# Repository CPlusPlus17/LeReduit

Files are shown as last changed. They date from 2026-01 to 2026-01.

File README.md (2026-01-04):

# 🏔️ Le Réduit

> **Autonomous Server: Solar, LoRa, WLAN & SSD. Your digital fortress for communication & situational awareness in emergencies.**






## 📖 About the Project

**Le Réduit** is a tribute to the Swiss National Redoubt strategy: A final, secure bastion when everything else fails.

This project documents the construction of a portable, energy-autonomous IT infrastructure inside a standardized Eurobox (Rako case). The system transforms a Raspberry Pi 4 into a **Tactical Operations Center (TOC)** for:
1.  **Situational Awareness & Command:** Real-time tracking and maps via TAK (Team Awareness Kit).
2.  **Secure Communication:** Encrypted chat and VoIP without the internet.
3.  **Radio Bridge:** Integration of LoRa (Meshtastic) into IP networks.
4.  **Emergency Power Supply:** Massive 100Ah battery capacity for days of operation without sun.

## ✨ Features

* **🔋 Energy Autonomy:** 100W/200W foldable solar panel + Victron SmartSolar MPPT 100/20 + 100Ah LiFePO4 battery.
* **📡 Off-Grid Communication:**
    * **LoRa:** Meshtastic Node (868 MHz) for communication over kilometers without mobile networks.
    * **LTE:** 4G/Cat-1 Bridge for hybrid connectivity when mobile networks are available.
    * **WLAN:** High-Power Access Point (Atheros AR9271) for local team devices.
* **🛡️ Edge Cluster:** Operates as a Single-Node Kubernetes Cluster (k3s) for maximum stability and "Infrastructure as Code".
* **💾 Hardware:** Passively cooled aluminum housing ("Armor Case"), insulated Rako case, IP-certified feedthroughs.

---

## 🛠️ Hardware (Bill of Materials)

A detailed shopping list can be found in [BOM.md](BOM.md). Here are the main components:

### ⚡ Energy
* **Battery:** Hypery Smart 12V LiFePO4 (100Ah, Bluetooth, BMS)
* **Solar:** 100W/200W Foldable Panel & Victron SmartSolar MPPT 100/20
* **Charging:** SAE External Port & PACO 10A Mains Charger (Backup)
* **Monitoring:** Digital Voltmeter & Fuse Holder (16AWG)

### 🖥️ Compute & Network
* **SBC:** Raspberry Pi 4 Model B (8GB RAM)
* **Storage:** Intenso TOP SSD (256GB, SATA III) + USB 3.0 Adapter
* **LoRa:** Heltec WiFi LoRa 32 V3 (ESP32)
* **WiFi:** Atheros AR9271 USB Adapter (with external antenna)
* **LTE:** USB A7670G LTE Cat 1 Dongle (Global Bands)
* **RTC:** DS3231 Real Time Clock (for timestamps without internet)

### 📦 Enclosure
* **Box:** Rako Container 600x400mm (60 Liters)
* **Structure:** Poplar plywood "Tech Deck" & Beechwood slat fixation
* **Insulation:** XPS Jackodur (20mm) for winter operation

---

## 🔌 Wiring & Architecture

The system follows a star-shaped 12V topology with central fusing.

See the [Detailed Wiring Schema](docs/wiring_schema.md) for the complete Mermaid diagram and pinout.

**Key Connections:**
* **Solar Input:** SAE Socket -> MPPT Controller
* **Load:** MPPT Load -> Main Switch -> Distributor -> DC-DC Converter -> Pi 4
* **Data:** SSD on USB 3.0 (Blue), Radio Modules on USB 2.0 (Interference Avoidance).

---

## 💻 Software Stack: "Edge Kubernetes Cluster"

The system runs as a **Single-Node Kubernetes Cluster** based on **k3s**. This enables "Self-Healing" capabilities (if a service crashes, it is restarted) and professional deployment via **Helm Charts**.

### 🏗️ Orchestration & Core
* **OS:** Raspberry Pi OS Lite (64-bit)
* **Cluster:** [k3s](https://k3s.io/) (Lightweight Kubernetes, optimized for Edge/IoT).
* **Package Management:** **Helm**. All services are defined as charts.
* **Ingress:** **Traefik** or **Nginx Ingress** for routing internal domains (e.g., `tak.reduit.local`).
* **Cert-Manager:** Manages internal self-signed certificates for TLS encryption.

### 🗺️ Situational Awareness
* **[OpenTAKServer](https://github.com/TakServer/OpenTakServer):**
    * Deployed via Helm Chart.
    * Central server for **ATAK** (Android Team Awareness Kit) clients.
    * Provides position data, markers, chat, and "Data Packages" to all connected end devices.
    * Hosts offline map tiles for the operational area.

### 💬 Secure Comms
* **[Matrix](https://matrix.org/):**
    * High-Performance Matrix Server (written in Rust).
    * Offers E2EE (End-to-End Encrypted) chats and file sharing.
    * Extremely resource-efficient compared to Synapse.
* **[Mumble](https://www.mumble.info/):**
    * VoIP server for tactical voice communication with low latency.
    * Works reliably even with unstable connections.

### 📡 Radio Bridge & Tools
* **[Meshtastic-Bridge](https://meshtastic.org/):**
    * Custom Pod that mirrors messages from the LoRa USB stick into a Matrix room via Python API.
    * Enables communication between WLAN users (ATAK/Matrix) and distant LoRa nodes.

---

## ⚠️ Safety Warning

This project uses large energy storage (LiFePO4 batteries).
* **Short Circuit Hazard:** A 100Ah battery can melt cables and cause fires in case of a short circuit. Fuses are mandatory!
* **BMS & Monitoring:** The LiFePO4 battery has an integrated BMS, but external fusing remains mandatory. Bluetooth monitoring allows checking cell status.

## 🤝 Contributing

Pull Requests for Helm Charts, 3D printed parts (mounts), or configuration tips are welcome!

## 📄 License

This project is published under the MIT License - see [LICENSE](LICENSE) file for details.

---
*Built in Switzerland 🇨🇭 for when it matters.*

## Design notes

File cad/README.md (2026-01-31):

# Tech Stack Foundation - CAD

This directory contains the OpenSCAD files for the 3D printed foundation.

## Files
- `foundation.scad`: Main design file.

## Usage
1. Install [OpenSCAD](https://openscad.org/).
2. Open `foundation.scad`.
3. Press `F5` to preview.
4. Press `F6` to render.
5. File -> Export -> Export as STL.

## Print Settings
- **Material**: PETG or ABS recommended for thermal stability.
- **Infill**: 20%+, Grid or Gyroid.
- **Orientation**: Flat on bed.

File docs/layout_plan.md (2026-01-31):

# 📐 Mechanical Layout Plan

**Part Specification**: 3D Printed Modular Plate (PETG/ASA)
**Total Size**: 550mm x 350mm (Split into segments for printing)
**Orientation**: Horizontal (Landscape) inside Rako box.

## Design Philosophy: "Clean Deck"
- All cables disappear immediately through holes near the components to the "Underdeck".
- High Power (12V) on the RIGHT side (nearer to cable glands usually).
- Logic (5V/Data) on the LEFT side.
- Airflow: Components spaced out.

## ASCII Layout Map

```text
       [   LEFT: 550mm   ]                                     [ RIGHT ]
  +-----------------------------------------------------------------------+
  |                                                                       |
  |   [ WIFI ANT  ]         [  SSD DRIVE  ]          [ MPPT CONTROLLER ]  |
  |     (Atheros)            (Velcro/Screw)             (Vertical Mount)  |
  |                                                                       |
  |                                                                       |
  |   [ RASPBERRY PI 4 ]    [  Heltec LoRa ]         [ FUSE UNIT ]        |
  |     (Armor Case)         (Stick/Case)             (Distributor)       |
  |                                                                       |
  |                         [ RTC / INA219 ]                              |
  |                          (Sensor Cluster)                             |
  |                                                                       |
  |                                                  [ MAIN SWITCH ]      |
  |                                                   (Panel Mount)       |
  |                                                                       |
  +-----------------------------------------------------------------------+
```

## Drilling & Mounting Guide

### 1. General Mounting Strategy
- **Material**: Printed in PETG or ASA to withstand summer temperatures inside the box.
- **Fasteners**: Use **M2.5/M3 Heat-Set Inserts** for all component mounts. Do not use self-tapping screws directly into plastic for frequently removed parts.
- **Segmentation**: The plate is likely printed in 2-4 sections (e.g., Dovetail or bolted joints) depending on printer volume (Voron 350 vs Prusa MK3).

### 2. The "Power Zone" (Right)
- **MPPT Controller**: Needs airflow. Mount slightly elevated.
- **Main Switch**: The printed plate should have a pre-modeled 20-23mm hole (check datasheet) or a snap-in rectangular cutout depending on the switch type.
- **Cable Pass-throughs**: Model these directly into the print with chamfered edges to protect cables.

### 3. The "Logic Zone" (Left/Center)
- **Raspberry Pi**: Use M2.5 heat-set inserts.
    - *USB*: Orientation matters! Point USB ports towards the "Cable Highway".
- **SSD**: Velcro is best for vibration dampening, or specific 3D printed cage.
- **Heltec LoRa**:
    - **Mounting**: **3D Printed Case** attached via **High-Temp Velcro / 3M Dual Lock**.
    - *Why*: Allows rapid field replacement of the unit without tools.
    - *Note*: Do not use standard sticky tape; use heat-resistant adhesive pads.

### 4. The "Cable Underworld" (Bottom side)
- Integrated cable tie anchors (zip tie slots) should be part of the print design.
- Run the 12V rails (Solar, Battery) along the edges.

## Dimensions Checklist
- **Pi 4**: ~88 x 58 mm
- **SSD**: ~100 x 70 mm
- **MPPT**: Victron SmartSolar 100/20 is approx. 100 x 113 x 40mm. Make sure to check the specific CAD model.

## 🕳️ External Rako Box Penetrations

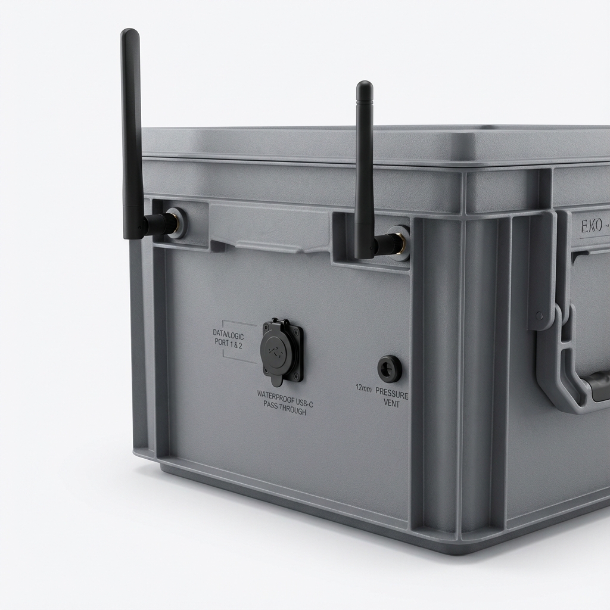
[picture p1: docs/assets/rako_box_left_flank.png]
Le Reduit Box Render


These are the drill holes required in the **grey plastic box itself**.
*Caution: Ensure holes are positioned below the stacking rim and clear of the handle recesses.*

### 1. Left Flank ("Data Zone")
*Position: Aligned with Internal Logic (Pi, LoRa, WiFi)*

Le Reduit Box Left Flank

- **2x SMB/SMA Antenna Mounts (LoRa & WiFi)**:
    - *Purpose*: External High-Gain Antennas.
    - *Hole*: 6.5mm (SMA) or 16mm (N-Type).
    - *Location*: Top corners (spaced apart).
- **USB Waterproof Pass-through**:
    - *Purpose*: External Data/Console access.
    - *Hole*: ~25mm (check diameter).
    - *Location*: **Mid-Section** (Elevated ~15cm from bottom) to protect against standing water.
- **Waterproof Vent Plug**:
    - *Purpose*: Passive cross-ventilation (Inlet).
    - *Hole*: 12mm (M12).
    - *Location*: **Mid-Height**, ~5cm from front edge.

### 2. Right Flank ("Power Zone")
*Position: Aligned with Internal Power (MPPT, Battery, Fuse)*

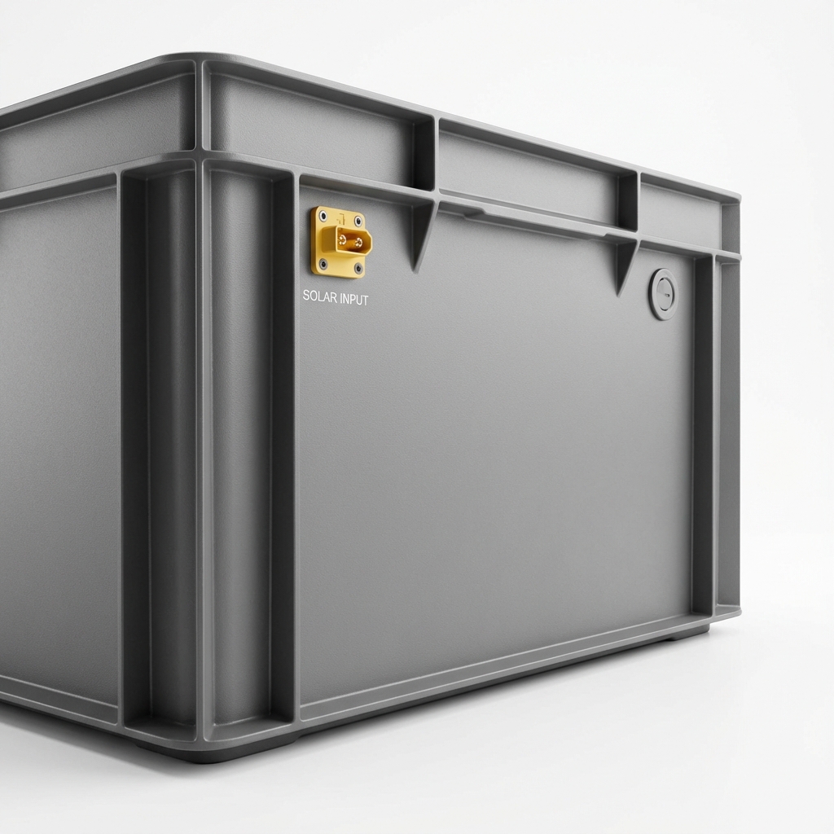
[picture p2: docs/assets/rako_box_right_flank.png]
Le Reduit Box Right Flank


- **Solar Input (XT60E-F)**:
    - *Purpose*: Connect Solar Panel.
    - *Hole*: Rectangular/Oval cutout (approx. 25mm x 15mm).
    - *Location*: High up, near MPPT.
- **Waterproof Vent Plug**:
    - *Purpose*: Passive cross-ventilation (Outlet).
    - *Hole*: 12mm (M12).
    - *Location*: ~5cm from back edge.

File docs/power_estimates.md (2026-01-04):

# Power Consumption & Battery Runtime Estimates

## Component Breakdown

| Component | Status | Current @ 5V | Power (Watts) | Note |
| :--- | :--- | :--- | :--- | :--- |
| **Raspberry Pi 4** | Idle | 0.6A | 3.0W | Aggressive Undervolt (-4) |
| **Raspberry Pi 4** | Load (4 Cores) | 1.2A | 6.0W | Aggressive Undervolt (-4) |
| **SSD (Intenso SATA)** | Avg | 0.3A | 1.5W | SATA III via USB adapter |
| **Alfa WiFi (AR9271)** | TX High Power | 0.5A | 2.5W | Unoptimized / Active TX |
| **Alfa WiFi (AR9271)** | Power Save | 0.04A | 0.2W | `power_save on` (Idle) |
| **Alfa WiFi (AR9271)** | Deep Sleep | 0.0A | 0.0W | USB Driver Unbound (`!wifi off`) |
| **Heltec LoRa V3** | RX/Idle | 0.1A | 0.5W | Peaks 0.2A during TX |
| **LTE Dongle (A7670G)** | Active/Data | 0.3A | 1.5W | Disabled by default |
| **GPS (BE-880)** | Active | 0.07A | 0.35W | Continuous tracking |
| **Sensors** | All Active | 0.05A | 0.25W | Negligible combined |

### Hardware Optimizations
*Optimizations configured via `setup/optimize_hardware.sh` included in estimates:*
*   **CPU Frequency**: **900MHz** (capped for power saving).
*   **Undervolting**: `over_voltage=-4` (aggressive power reduction).
*   **WiFi Power Management**: `power_save on` (Default) & Driver Unbind (Deep Sleep).
*   **Peripherals**: HDMI, Audio, Bluetooth, & Internal WiFi **DISABLED**.

### Total Scenarios

1.  **Deep Sleep (Stealth)**
    *   Pi Idle, SSD Idle, WiFi OFF (USB Unbound), LoRa RX.
    *   **~4.5 Watts** (0.9A @ 5V)
    
2.  **Sentry Mode (Connected)**
    *   Pi Idle, SSD Idle, WiFi ON (Power Save), LoRa RX.
    *   **~5.0 Watts** (1.0A @ 5V)

3.  **Tactical Mode (Active)**
    *   Pi Load, Map Server busy, High Power WiFi TX, LoRa TX, LTE Active.
    *   **~13.5 Watts** (2.7A @ 5V)

## Battery Runtime (100Ah LiFePO4)

*   **Nominal Capacity**: 100Ah @ 12.8V = 1280Wh
*   **Usable Capacity (LiFePO4)**: 90% Depth of Discharge = **1152Wh**
*   **DC-DC Efficiency**: ~90% (12V to 5V conversion)
*   **Effective Energy**: **~1036Wh**

| Scenario | Power | Runtime (hrs) | Runtime (Days) |
| :--- | :--- | :--- | :--- |
| **Deep Sleep (4.5W)** | 4.5W | ~230h | **~9.5 Days** |
| **Sentry (5.0W)** | 5.0W | ~207h | **~8.5 Days** |
| **Active (13.5W)** | 13.5W | ~76h | **~3.2 Days** |

## Solar Replenishment (100W Panel)

*   **Summer (Sunny)**: ~400-500Wh / day.
    *   **Result**: Fully self-sustaining in Sentry/Deep Sleep. Massive positive energy balance.
*   **Winter (Overcast)**: ~50-100Wh / day.
    *   **Result**: Extends runtime by +10-20%, but **battery will deplete after ~4-5 days**.

### Recommendations
1.  **Disable High Power WiFi** (AR9271) when not needed.
2.  **Shutdown Strategy**: The LiFePO4 battery's BMS protects it, but a software shutdown at ~12.0V is recommended to avoid sudden power loss.

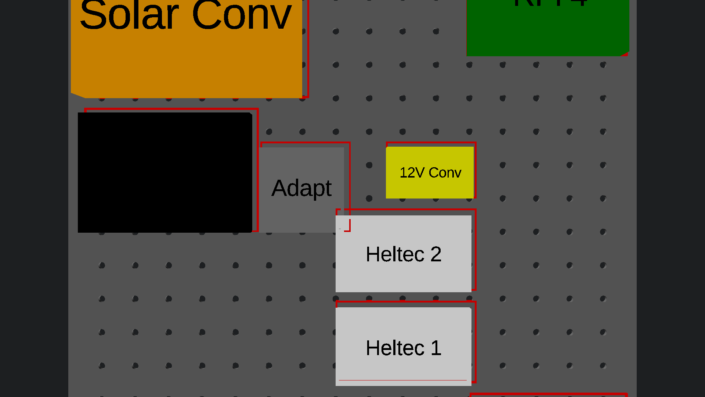
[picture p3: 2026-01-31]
cad/render_top.png

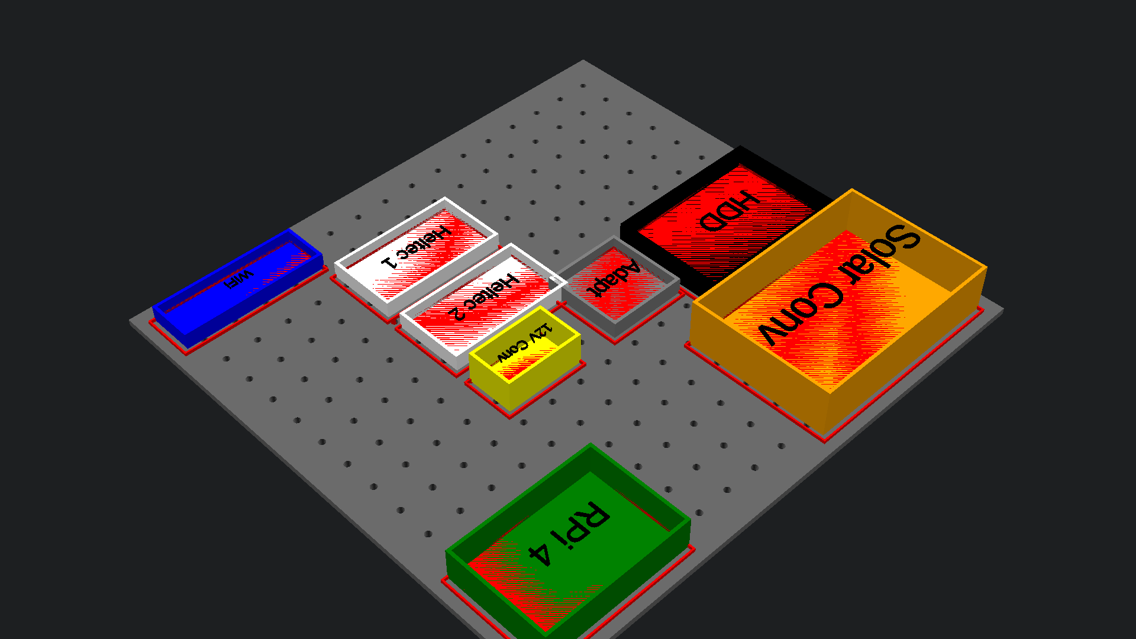
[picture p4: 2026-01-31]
cad/render_iso.png

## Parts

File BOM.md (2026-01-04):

# 🛒 Bill of Materials (BOM) - Full Inventory

## 🏗️ Mechanical & Housing (OBI / Local)

| Component | Description | Art. Nr. | Status |
| :--- | :--- | :--- | :--- |
| **Container** | Rako Behälter 60 Liter (600x400mm) | 2128965 | ✅ In Stock |
| **Lid** | Rako Deckel 60x40 cm | 2129005 | ✅ In Stock |
| **Backplate** | Sperrholzplatte Pappel A/B FSC® (600x600x8mm) | 3677028 | ✅ In Stock |
| **Rails** | Rechteckleiste Buche (15x20x1000mm) | 1402577 | ✅ In Stock |
| **Insulation** | XPS Dämmplatte Jackodur KF300 (20mm) | 4670402 | ✅ In Stock |
| **Glue** | UHU Poly Max High Grip Express | 4939443 | ✅ In Stock |
| **Screws/Washers** | Spax Black / Polyamide Washers | Multiple | ✅ In Stock |
| **Cleaner/etc** | Aceton, Sandpaper | Multiple | ✅ In Stock |

## 📦 AliExpress Inventory (Detailed Checklist)

### ⚡ Energy & Power Management
1.  **Solar Panel**: 100W/200W Foldable Panel
2.  **Charge Controller**: Victron Energy SmartSolar MPPT 100/20
3.  **Battery**: Hypery Smart 12V 100Ah LiFePO4 (Bluetooth, BMS)
4.  **DC-DC Converter**: SZWENGAO 12V to 5V 3A (15W) USB-C
5.  **Main Switch**: 12V 23mm Round Rocker Switch (LED)
6.  **Secondary Switch**: 1Pc On/Off SPST Round Rocker
7.  **Fuses**: Standard Blade Fuse Inserts (Zinc)
8.  **Fuse Holder**: Waterproof 32V Inline Fuse Holder
9.  **Battery Connectors**: XT60H (Yellow) with Sheath Housing
10. **Panel Connectors**: XT60E-F (Panel Mount Socket)
11. **Dust Protection**: XT60 Dust Covers
12. **Aux Power**: SAE Weatherproof Connector Socket
13. **USB Outlet**: 12V PD & QC3.0 Dual USB Charger Socket
14. **Monitoring A**: INA219 I2C Current Sensor (x2)
15. **Monitoring B**: 0.28 Inch DC LED Digital Voltmeter
16. **Monitoring C**: DS18B20 Waterproof Temperature Sensor (1-Wire)
17. **Monitoring D**: BME280 (Humidity/Pressure/Temp) - I2C
18. **Monitoring E**: MPU6050 (Accelerometer/Gyro) - I2C
19. **Security**: MC-38 Wired Door/Window Sensor (Reed Switch)
20. **Audio**: Active Buzzer Module (3.3V-5V)
21. **Monitoring F**: BH1750 Light Sensor (Lux) - I2C
22. **Wire**: Super Soft 2 Pin Silicone Wire (14AWG & thinner)

### 🧠 Computing & RF
21. **LoRa Board**: Heltec WiFi LoRa 32 V3 (868MHz)
22. **LoRa Antenna**: 868MHz External Antenna
23. **GPS Module**: BE-880 (Beitian) GPS + Compass (UART/I2C)
24. **WiFi Adapter**: Atheros AR9271 High Power Stick
24. **RF Cabling**: U.FL to SMA Pigtails (for external antennas)
25. **Data Cable**: USB 3.2 Gen2 Cable (USB-A to USB-C)
26. **Timekeeping**: DS3231 RTC Module
27. **LTE Dongle**: USB A7670G LTE Cat 1 (Global Bands)
28. **LTE Antenna**: YE0003AA 699-5000MHz Multi-band
29. **LTE Pigtail**: SMA to IPX-1 Pigtail (RP-SMA to U.fl)

### 🕹️ Interface & Enclosure Parts
27. **Shutdown Button**: 12mm Momentary Push Button
28. **Data Feedthrough**: USB 3.0 Waterproof Panel Mount
29. **USB-C Feedthrough**: USB 3.1 Type C Panel Mount Coupler
30. **Ventilation**: Waterproof Vent Plug (Pressure equalization)
31. **Sealing**: EPDM Noise Insulation / Sealing Tape
32. **Cable Entry**: Nylon Cable Gland Kit (PG9)

### 🔩 Mounting & Small Hardware
33. **Spacers**: 165pcs Black Nylon Spacer Kit (M2.5/M3)
34. **Washers**: Nylon Black Washers
35. **Terminals**: Ring Terminal Connectors (for Battery)
36. **Insulation**: Black Heat Shrink Tube Kit
37. **Jumpers**: 20Pin 30cm Jumper Wires (Female-Female/Male-Female)
38. **Management**: Car Cable Clamp Accessories (Adhesive)
39. **Ties**: Plastic Clamping Collar (Cable Ties)
40. **Mounting Tape**: 3M Double Sided Tape
41. **Velcro**: Hook and Loop Fastener
42. **Straps**: Webbing Tensioner Buckles

### 🛠️ Tools
43. **Soldering Iron**: FNIRSI HS-01
44. **Soldering Aid**: Flux & Paste
45. **Holder**: Helping Hands
46. **Drilling**: HSS Titanium Step Drill Bit

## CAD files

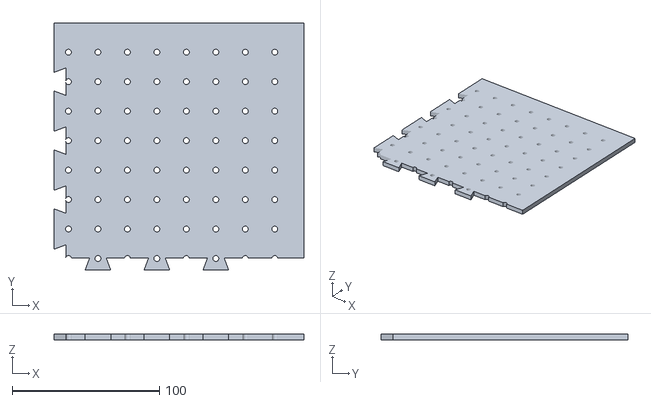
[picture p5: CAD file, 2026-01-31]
cad/part_2_top_right.stl
169.6 x 167.6 x 4.00

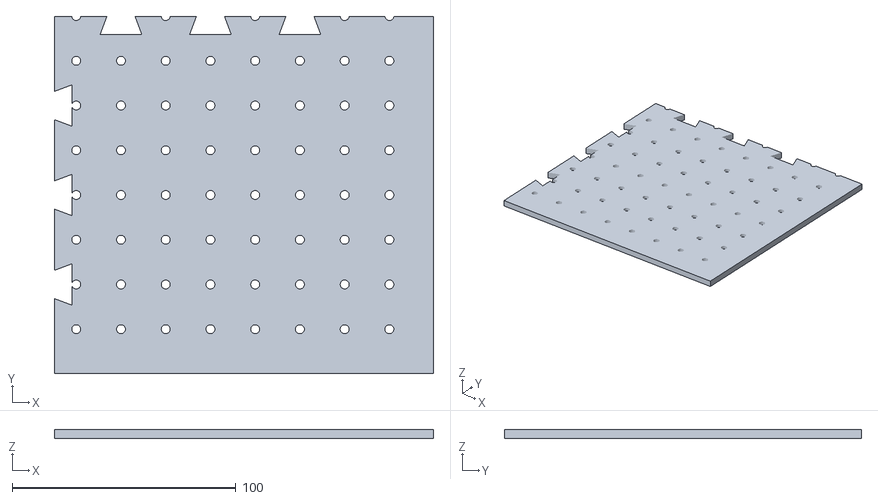
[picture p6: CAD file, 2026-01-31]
cad/part_4_bottom_right.stl
169.6 x 159.6 x 4.00

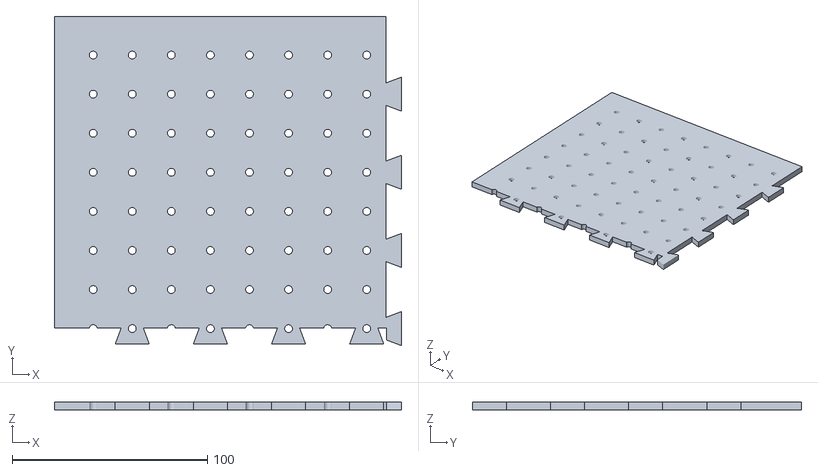
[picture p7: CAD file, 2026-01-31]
cad/part_1_top_left.stl
177.6 x 168.5 x 4.00

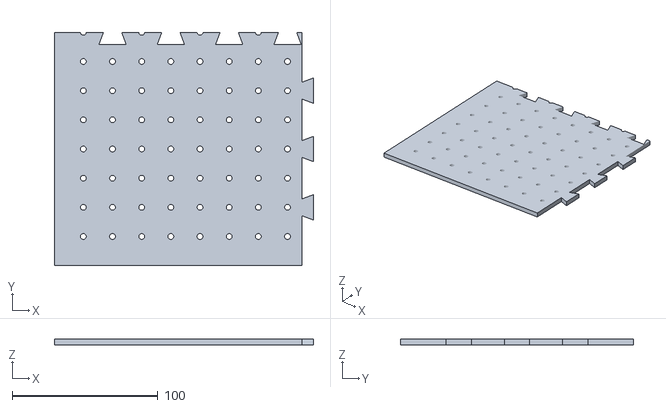
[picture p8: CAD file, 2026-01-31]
cad/part_3_bottom_left.stl
177.6 x 159.6 x 4.00

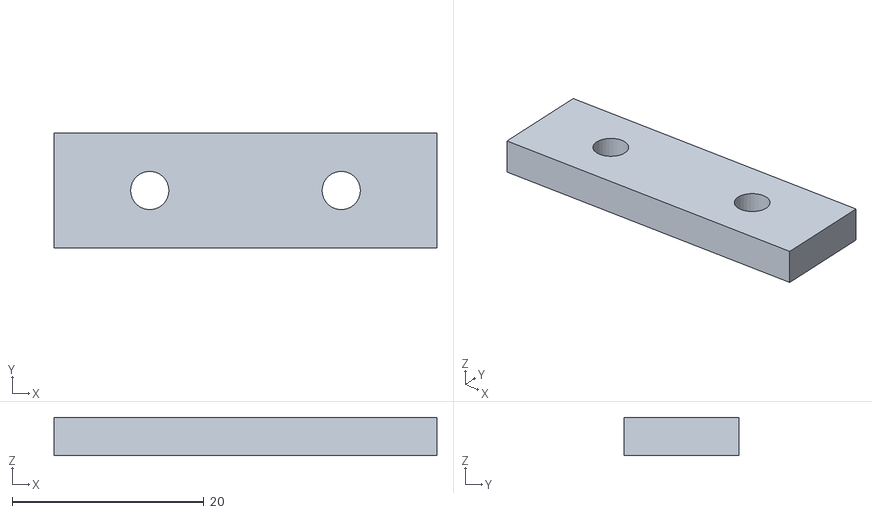
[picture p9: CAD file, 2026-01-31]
cad/joiner_strip.stl
40.0 x 12.0 x 4.00

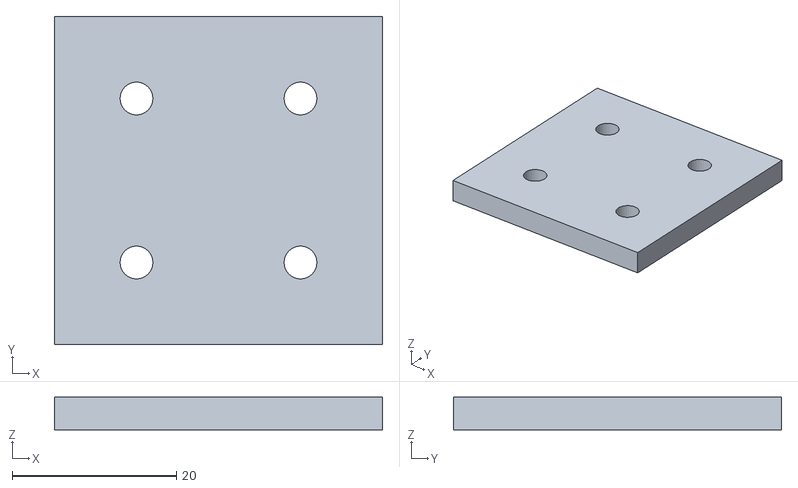
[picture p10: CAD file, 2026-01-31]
cad/joiner_cross.stl
40.0 x 40.0 x 4.00

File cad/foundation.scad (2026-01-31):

// Tech Stack Foundation
// Total dimensions: 340mm x 320mm

// --- Global Resolution ---
// --- Global Resolution ---
$fn = 30;

// --- Dimensions (mm) ---
total_width = 340;
total_depth = 320;
plate_thickness = 4;
wall_height = 8; 

// Component Dimensions [w, d, h_mock]
dim_solar = [130, 90, 30];
dim_hd = [100, 70, 15]; // Assumed 100x70
dim_hd_adapter = [50, 50, 10]; 
dim_pi = [92, 65, 20];
dim_heltec = [80, 45, 10];
dim_wifi = [90, 30, 10];
dim_conv_12v = [50, 30, 20];

// Spacing
margin = 10;

// --- Render Control ---
// CLI override support: pass -D cli_quadrant=X
cli_quadrant = undef;
render_quadrant = (cli_quadrant == undef) ? -1 : cli_quadrant; 
show_mocks = (render_quadrant == -1);

// --- Modules ---

module mounting_grid() {
    // Generates a grid of 4mm holes (2D circles)
    grid_spacing = 20;
    for (x = [grid_spacing : grid_spacing : total_width - grid_spacing]) {
        for (y = [grid_spacing : grid_spacing : total_depth - grid_spacing]) {
            translate([x, y])
                circle(d = 4);
        }
    }
}

module joining_tabs() {
     // Tabs to join the 4 quadrants with M3 screws
     // Vertical seam
     for (y = [total_depth/4, total_depth*0.75]) {
         translate([total_width/2, y, plate_thickness/2]) {
             difference() {
                 cube([12, 20, plate_thickness], center=true);
                 translate([3, 0, -5]) cylinder(h=20, d=3.5); // Hole right
                 translate([-3, 0, -5]) cylinder(h=20, d=3.5); // Hole left
             }
         }
     }
     // Horizontal seam
     for (x = [total_width/4, total_width*0.75]) {
         translate([x, total_depth/2, plate_thickness/2]) {
             difference() {
                 cube([20, 12, plate_thickness], center=true);
                 translate([0, 3, -5]) cylinder(h=20, d=3.5); // Hole top
                 translate([0, -3, -5]) cylinder(h=20, d=3.5); // Hole bottom
             }
         }
     }
     // Center cross
     translate([total_width/2, total_depth/2, plate_thickness/2]) {
         difference() {
             cube([20, 20, plate_thickness], center=true);
             translate([5, 5, -5]) cylinder(h=20, d=3.5);
             translate([-5, 5, -5]) cylinder(h=20, d=3.5);
             translate([5, -5, -5]) cylinder(h=20, d=3.5);
             translate([-5, -5, -5]) cylinder(h=20, d=3.5);
         }
     }
}

module base_plate() {
    color("DimGray") 
    linear_extrude(plate_thickness)
        difference() {
            square([total_width, total_depth]);
            mounting_grid();
        }
    //joining_tabs(); // To implement properly, tabs need to be part of the split logic or added to specific quadrants
}

module component_box(dim, label_text, color_code="Silver") {
    w = dim[0];
    d = dim[1];
    h = dim[2];
    
    if (show_mocks) {
        translate([0,0,plate_thickness]) {
            color(color_code) {
                difference() {
                    cube([w, d, h]);
                    translate([2, 2, 2]) cube([w-4, d-4, h]);
                }
            }
            color("Black")
            translate([w/2, d/2, h])
            linear_extrude(1)
            text(label_text, size=min(w,d)/5, halign="center", valign="center");
        }
        
        // Footprint marker retention wall
        color("Red")
        difference() {
             cube([w+4, d+4, plate_thickness + 2]);
             translate([2, 2, -1]) cube([w, d, plate_thickness + 5]);
             translate([1, 1, -1]) cube([w+2, d+2, plate_thickness + 5]); // Thin wall
        }
    }
}

// --- Layout ---

module layout() {
    // 1. Solar Converter (Top Left)
    translate([margin, total_depth - dim_solar[1] - margin, 0])
        component_box(dim_solar, "Solar Conv", "Orange");

    // 2. Raspberry Pi (Top Right)
    translate([total_width - dim_pi[0] - margin, total_depth - dim_pi[1] - margin, 0])
        component_box(dim_pi, "RPi 4", "Green");

    // 3. Hard Drive & Adapter (Left, below Solar)
    translate([margin, total_depth - dim_solar[1] - margin*2 - dim_hd[1], 0]) {
        component_box(dim_hd, "HDD", "Black");
        translate([dim_hd[0] + 5, 0, 0]) 
            component_box(dim_hd_adapter, "Adapt", "Gray");
    }

    // 4. Heltec V2 x2 (Center area)
    translate([margin + dim_hd[0] + margin + 40, margin + 40, 0]) {
        component_box(dim_heltec, "Heltec 1", "White");
        translate([0, dim_heltec[1] + margin, 0])
            component_box(dim_heltec, "Heltec 2", "White");
    }

    // 5. Wifi Stick (Bottom Right)
    translate([total_width - dim_wifi[0] - margin, margin, 0])
        component_box(dim_wifi, "WiFi", "Blue");

    // 6. Converter 12V (shifted right to avoid Adapter overlap)
    translate([total_width/2 + 20, total_depth/2, 0])
        component_box(dim_conv_12v, "12V Conv", "Yellow");
}

module full_assembly() {
    base_plate();
    layout();
}

// --- Puzzle Config ---
cut_gap = 0.2; // Tolerance for fit

module dovetail_tab(pos, angle) {
    // A single dovetail tab
    // pos: [x, y] of the base center
    // angle: 0 for X+ pointing, 90 for Y+ pointing, etc.
    size = 12; // Width of neck
    tip = 18;  // Width of tip
    len = 8;   // Length of tab
    
    translate(pos)
        rotate(angle)
            polygon([
                [0, -size/2], [len, -tip/2], 
                [len, tip/2], [0, size/2]
            ]);
}

module puzzle_mask_2d(q) {
    // Generate the 2D shape for the quadrant with puzzle cuts
    
    x_mid = total_width / 2;
    y_mid = total_depth / 2;
    
    // Base logical region logic
    logic_rect = (q==0) ? [0, y_mid, x_mid, y_mid] : // x, y, w, h
                 (q==1) ? [x_mid, y_mid, x_mid, y_mid] :
                 (q==2) ? [0, 0, x_mid, y_mid] :
                          [x_mid, 0, x_mid, y_mid];
                          
    offset(delta = -cut_gap) {
        difference() {
            union() {
                 translate([logic_rect[0], logic_rect[1]]) square([logic_rect[2], logic_rect[3]]);
                 
                 // Vertical Seam Tabs (on x=x_mid)
                 // Tabs stick from Left (Q0, Q2) into Right (Q1, Q3)
                 if (q == 0 || q == 2) { 
                     for(y = [40 : 40 : total_depth-40]) {
                         if ( (q==0 && y >= y_mid) || (q==2 && y < y_mid) )
                            dovetail_tab([x_mid, y], 0);
                     }
                 }
                 
                 // Horizontal Seam Tabs (on y=y_mid)
                 // Tabs stick from Top (Q0, Q1) into Bottom (Q2, Q3)
                 if (q == 0 || q == 1) {
                     for(x = [40 : 40 : total_width-40]) {
                         if ( (q==0 && x < x_mid) || (q==1 && x >= x_mid))
                            dovetail_tab([x, y_mid], 270); // Pointing Down
                     }
                 }
            }
            
            // Subtractions for sockets
            // If I am Right side (Q1, Q3), cut holes for Left's tabs
            if (q == 1 || q == 3) {
                 for(y = [40 : 40 : total_depth-40]) {
                     if ( (q==1 && y >= y_mid) || (q==3 && y < y_mid) )
                        dovetail_tab([x_mid, y], 0);
                 }
            }
            // If I am Bottom side (Q2, Q3), cut holes for Top's tabs
            if (q == 2 || q == 3) {
                 for(x = [40 : 40 : total_width-40]) {
                     if ( (q==2 && x < x_mid) || (q==3 && x >= x_mid))
                        dovetail_tab([x, y_mid], 270);
                 }
            }
        }
   }
}


module quadrant(q) {
    intersection() {
        full_assembly();
        linear_extrude(100, center=true) puzzle_mask_2d(q);
    }
}

// --- Main Render ---
if (render_quadrant == -1) {
    full_assembly();
} else {
    quadrant(render_quadrant);
}

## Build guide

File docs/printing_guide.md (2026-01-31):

# 🖨️ Printing Guide for Le Réduit Platform

This guide describes how to manufacture the internal mounting platform using 3D printing. This replaces the traditional plywood approach with a modular, technical design.

## 🧵 Material Selection

### ✅ Recommended: ASA (Acrylonitrile Styrene Acrylate)
*   **Why**: UV resistant, high heat resistance (~95°C), chemically resistant. Perfect for outdoor/enclosed electronics.
*   **Finish**: Matte Black looks professional and hides layer lines.

### ⚠️ Acceptable: PETG (Polyethylene Terephthalate Glycol)
*   **Why**: Good heat resistance (~75°C), easy to print, flexible.
*   **Warning**: If the Rako box sits in direct blistering sunlight, internal temps *might* soften PETG under load. For shaded deployment, it is fine.

### ⛔️ Avoid: PLA (Polylactic Acid)
*   **Why**: Softens at ~55-60°C. A closed black box in the sun will exceed this. Your platform **and your printed cases** will warp and fail.
*   **Verdict**: Do not use PLA for *anything* inside the box.

## 🧵 Component Specifics (Cases/Mounts)
*   **Recommended**: **ASA** (Matches the plate, highest heat resistance).
*   **Acceptable**: **PETG** (Good for small parts, snap-fits are durable).

## � Adhesives & Fasteners

For components mounted with **Velcro** (like the SSD or Heltec Case), you must be careful about thermal failure.

### ⚠️ Warning: Adhesive Creep
*   Inside a black Rako box in the sun, temperatures can hit **60°C+**.
*   **Standard Velcro Adhesive**: Will soften and slide ("creep") or detach completely.
*   **Solution**: Use **3M Dual Lock (High Temp)** or **Velcro Industrial Strength (High Heat)**. Look for ratings above 90°C.

## �📐 Segmentation & Printing Strategy

The total size is **550mm x 350mm**, which exceeds most hobbyist build volumes.

### Option A: Large Format (Voron 2.4 350 / Modix)
*   If you have a 350x350mm bed, you can print it in **2 segments** (Left/Right).
*   Join method: M3 bolts + Nuts or dovetail slide.

### Option B: Standard Format (Prusa MK3/4 / Bambu X1C)
*   Standard bed (~250x210mm).
*   Requires printing in **4-6 Segments**.
*   **Assembly**: The CAD design features 'Puzzle' connectors or bolt flanges. Use Superglue (Cyanoacrylate) for permanent bonds or M3 bolts for modularity.

## ⚙️ Print Settings

*   **Nozzle**: 0.4mm or 0.6mm (0.6mm recommended for speed and strength).
*   **Perimeters (Walls)**: 4 to 5 (Crucial for screw holding strength).
*   **Top/Bottom Layers**: 4.
*   **Infill**: 20-30% Grid or Gyroid (Structural rigidity).
*   **Supports**: Minimal. Design should be chamfered to avoid supports.

## �️ Printer-Specific Tips

### Bambu Lab (P1S / X1C)
*   **PETG**:
    *   **Plate**: Use **Textured PEI Plate**. *Warning: PETG can fuse permanently to smooth PEI or Cool Plates without glue stick.*
    *   **Door**: Keep closed to avoid warping nearby drafts, but ensure chamber fan is on (default profile handles this).
*   **ASA**:
    *   **Plate**: Textured or Smooth PEI (with glue).
    *   **Enclosure**: **Keep CLOSED**. ASA needs a warm chamber (~40-50°C) to prevent warping and layer splitting. Pre-heat the chamber by running the bed at 100°C for 10-15 mins before starting if printing large parts.
    *   **Brim**: **Highly Recommended** (5-10mm) for large flat parts like the mounting plate to prevent corners from lifting.
    *   **Ventilation & Fumes**: ASA releases **Styrene** (smells like burning plastic).
        *   **Standard**: Open a window.
        *   **Basement/Enclosed**: Use an **Activated Carbon Filter**. The P1S has a small one, but it's often not enough.
        *   **Upgrade**: Look into printing a **"BentoBox"** (internal recirculating carbon filter).
        *   **Upgrade**: Look into printing a **"BentoBox"** (internal recirculating carbon filter).
            *   *Search*: **"BentoBox V2.0"** by **thrutheframe** on **MakerWorld** or **Printables**.
            *   *Note*: Requires 5015 fans and Acid-Free Activated Carbon pellets.
        *   **Grow Tent**: If you have one, **use it**. It is perfect for containing fumes and keeping the printer warm. Just unzip it after the smell settles.

## �🔧 Post-Processing

### Heat-Set Inserts
*   The design relies on **M2.5 and M3 Heat-Set Inserts** (Short type).
*   **Process**:
    1.  Set soldering iron to ~250°C (for ASA/PETG).
    2.  Place insert on the hole.
    3.  Gently press down with the iron until flush.
    4.  Use a flat object to hold it flush while cooling.

### Assembly
1.  Assemble the plate segments.
2.  Install all heat-set inserts.
3.  Perform a "Dry Fit" in the Rako box to ensure tolerances.

## 🔩 Hardware Reference (Heat-Set Inserts)

Based on the **OD 3.5mm** (M2.5) and **OD 4.0mm** (M3) kit:

| Screw Size | Insert OD | Recommended CAD Hole Ø | Depth | Usage |
| :--- | :--- | :--- | :--- | :--- |
| **M2.5** | 3.5 mm | **3.2 - 3.3 mm** | 4-5 mm | Raspberry Pi, HATs |
| **M3** | 4.0 mm | **3.6 - 3.7 mm** | 5-6 mm | Mounts, Clips, SSD |
| **M2** | 3.5 mm | **3.2 - 3.3 mm** | 3-4 mm | Small Sensors (Optional) |

> [!TIP]
> **Hole Sizing**: For 3D printing, holes often shrink slightly. Designing the hole at **OD - 0.3mm** usually provides a perfect interference fit for heat setting.

---
**Happy Printing!**

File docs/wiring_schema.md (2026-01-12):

# 🔌 Wiring Schema - Le Réduit

## ⚡ Power Distribution Topology (12V Base)

The system uses a **Central Post** topology. All main loads connect to the Load Output of the MPPT controller (if current limit permits) or directly to the battery with a low-voltage disconnect (LVD). *Note: Most MPPT Load outputs are limited (e.g., 20A). Ensure total draw is within limits. The Pi and Accessories are fine.*

> [!WARNING]
> **Voltage Check**: The solar panel voltage (Voc) MUST NOT exceed 26V, or the INA219 sensor will be destroyed.

```mermaid
graph TD
    Solar["Solar Panel 100W+"] -- XT60 --> INA_Solar["INA219 Sensor 1<br>(Address 0x40)"]
    INA_Solar --> MPPT[MPPT Charge Controller]
    
    Battery["12V 100Ah LiFePO4 (Hypery)"] -- Fuse 30A --> MPPT
    
    MPPT -- Load Output --> MainSwitch[Main Rocker Switch]
    MainSwitch --> FuseBox["Fuse Box / Distributor"]
    
    subgraph "System Load (Monitored)"
        FuseBox -- Fuse 5A --> INA_Sys["INA219 Sensor 2<br>(Address 0x41/0x44)"]
        INA_Sys --> Buck["12V to 5V 3A USB-C"]
        Buck --> Pi[Raspberry Pi 4]
    end
    
    subgraph "Aux Outputs"
        FuseBox -- Fuse 10A --> SAE[SAE External Port]
        FuseBox -- Fuse 5A --> USB_Hub["12V USB Hub / Outlet"]
    end
```

## 📍 Raspberry Pi 4 Pinout

We use the GPIO header for I2C (Sensors & RTC) and Setup Buttons.

| Pin | GPIO | Function | Connection | Note |
| :--- | :--- | :--- | :--- | :--- |
| 1 | 3.3V | 3.3V Power | INA219 VCC, DS3231 VCC | Logic Voltage (NOT 5V!) |
| 3 | GPIO 2 | **SDA** (I2C) | INA219 SDA, DS3231 SDA, BE-880 SDA | I2C Data Bus |
| 5 | GPIO 3 | **SCL** (I2C) | INA219 SCL, DS3231 SCL, BE-880 SCL | I2C Clock |
| 6 | GND | Ground | All GNDs | Common Ground |
| 7 | GPIO 4 | **1-Wire** | DS18B20 Data | Requires 4.7kΩ Pull-Up Resistor between 3.3V and Data |
| 8 | GPIO 14 | **TXD** (UART) | BE-880 RX | GPS Data Receive |
| 10 | GPIO 15 | **RXD** (UART) | BE-880 TX | GPS Data Transmit |
| 11 | GPIO 17 | **Intrusion** | MC-38 Reed Switch | Connect between GPIO 17 & GND (Internal Pull-Up enabled) |
| 13 | GPIO 27 | **Buzzer** | Active Buzzer (+) | Connect (+) to GPIO 27, (-) to GND |
| 9 | GND | Ground | Button GND | |
| 39 | GND | Ground | | |
| 5V | 5V | 5V Power | Fan (Optional), BE-880 VCC | GPS needs 5V (mostly) or 3.3V check spec |
| 37 | GPIO 26| Shutdown | Button (NO) | Connect between GPIO 26 & GND |

### I2C Address Map
The I2C bus allows multiple devices. They need unique addresses.
- **0x40**: INA219 **Sensor 1** (Solar Input) - Keep Default (No Solder).
- **0x41**: INA219 **Sensor 2** (System Load) - **SOLDER BRIDGE A0**.
- **0x68**: DS3231 Real Time Clock (Fixed Default)
- **0x69**: MPU6050 (Accelerometer) - **REQUIRED**: Connect **AD0** pin to **3.3V** to set this address.
- **0x1E**: BE-880 Internal Compass (HMC5883L)
- **0x23**: BH1750 Light Sensor (Default)
- **0x76** or **0x77**: BME280

## 📡 Data Connections (USB)
To avoid interference between USB 3.0 (high frequency noise) and 2.4GHz devices (though we use 868MHz/5GHz mostly), spacing matters.

- **USB 3.0 (Blue)**: 
    - Top: SSD Adapter
    - Bottom: Heltec LoRa V3 (RNode) - **Own SMA Antenna**
- **USB 2.0 (Black/White)**: 
    - Top: Atheros AR9271 WiFi (External connection via extension recommended)
    - Bottom: Heltec LoRa V3 (Meshtastic) - Shared/Main Antenna

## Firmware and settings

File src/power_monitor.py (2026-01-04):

#!/usr/bin/env python3
import time
import board
import busio
from adafruit_ina219 import INA219
import logging
import csv
import json
from datetime import datetime
import os
import requests
import socket
from influxdb_client import InfluxDBClient, Point, WritePrecision
from influxdb_client.client.write_api import SYNCHRONOUS
from w1thermsensor import W1ThermSensor, SensorNotReadyError

import math
from adafruit_bme280 import basic as adafruit_bme280
import math
import subprocess
from adafruit_bme280 import basic as adafruit_bme280
from adafruit_mpu6050 import MPU6050
import adafruit_bh1750
import RPi.GPIO as GPIO
import smbus2

# --- Configuration ---
I2C_ADDR_SOLAR = 0x40
I2C_ADDR_SYSTEM = 0x41
I2C_ADDR_BME = 0x76  # or 0x77
I2C_ADDR_MPU = 0x69 # AD0 pulled HIGH (3.3V) to avoid conflict with DS3231 (0x68)
I2C_ADDR_COMPASS = 0x1E # HMC5883L
I2C_ADDR_BH1750 = 0x23

# GPIO Config
PIN_SHUTDOWN = 26
PIN_LID_SENSOR = 17
PIN_BUZZER = 27

LOG_FILE = "/var/log/reduit_power.csv"
SAMPLE_INTERVAL_ACTIVE = 5
SAMPLE_INTERVAL_ECO = 30
current_sample_interval = SAMPLE_INTERVAL_ACTIVE

SHUTDOWN_VOLTAGE = 11.5
SHUTDOWN_GRACE_PERIOD_SAMPLES = 3
TAMPER_THRESHOLD_G = 0.5
# ... (imports)

# --- Configuration ---
# ...
# ...
WIFI_INTERFACE = "wlan1"
WIFI_TXPOWER_DBM = int(os.getenv("WIFI_TXPOWER_DBM", "10"))
# USB Bus ID for the Atheros Stick (Run 'lsusb -t' or check /sys/bus/usb/devices/ to find this)
# Example: "1-1.3" or similar. If empty, deep sleep is skipped.
WIFI_USB_ID = os.getenv("WIFI_USB_ID", "")
# Path to the driver to unbind from (usually ath9k_htc)
WIFI_DRIVER_PATH = os.getenv("WIFI_DRIVER_PATH", "/sys/bus/usb/drivers/ath9k_htc")

# --- Alert Thresholds ---
# --- Alert Thresholds ---
THRESH_VOLT_LOW_WARN = 12.0
THRESH_TEMP_HIGH = 50.0
THRESH_TEMP_LOW = 0.0
THRESH_HUMIDITY_HIGH = 80.0
THRESH_LIGHT_LEAK = 10.0 # Lux inside closed box

# --- Auto Mode Thresholds ---
AUTO_MODE_ENABLED = os.getenv("AUTO_MODE_ENABLED", "1") == "1"
THRESH_SOLAR_HIGH = 15.0 # Watts (Go Tactical)
THRESH_BATT_HIGH = 13.2  # Volts (Go Tactical)
THRESH_SOLAR_LOW = 5.0   # Watts (Go Sentry)
THRESH_BATT_LOW = 12.5   # Volts (Go Sentry)
HYSTERESIS_SAMPLES = 12  # 12 * 5s = 60s


# --- Alert Manager Class ---
class AlertManager:
    def __init__(self):
        self.states = {} # key -> last_alert_time
        self.cooldown = 3600 # 1 hour cooldown for persistent conditions
        
    def check(self, key, condition, message, is_critical=False):
        timestamp = time.time()
        last_time = self.states.get(key, 0)
        
        if condition:
            # If condition is met, check if we should alert
            if (timestamp - last_time) > self.cooldown:
                priority = "🔴 CRITICAL" if is_critical else "⚠️ WARNING"
                full_msg = f"{priority}: {message}"
                send_matrix_alert(full_msg)
                logger.warning(full_msg)
                if is_critical: buzz(1.0, 1)
                else: buzz(0.2, 2)
                self.states[key] = timestamp
        else:
            # Reset state if condition clears (optional, allows re-alert immediately if it happens again)
            # Maybe keep hysteresis? For now, simple clear.
            if key in self.states and (timestamp - last_time) > 60: # debounce clear
                # Optionally notify recovery? "Condition Cleared"
                # send_matrix_alert(f"✅ Resolved: {key}")
                pass
            # We don't remove the key immediately to prevent flapping, 
            # but effectively the condition is False so we won't alert.
            pass

alert_manager = AlertManager()

# ... (rest of helper functions)

def check_sensor_thresholds(data):
    # 1. Voltage Warning (distinct from Shutdown)
    # Only if system_volts is > 5 (valid reading)
    volts = data['system_volts']
    if volts > 5.0:
        alert_manager.check("batt_low", volts < THRESH_VOLT_LOW_WARN, 
                            f"Battery Low: {volts:.2f}V (Approaching Shutdown)", is_critical=False)
    
    # 2. Temperature
    temp = data['temperature']
    # Filter valid reading (sometimes 85 is error/init code for DS18B20? actually 0 is suspicious too if invalid)
    alert_manager.check("temp_high", temp > THRESH_TEMP_HIGH, 
                        f"High Temperature: {temp:.1f}°C", is_critical=True)
    alert_manager.check("temp_low", temp < THRESH_TEMP_LOW, 
                        f"Freezing Temperature: {temp:.1f}°C", is_critical=False)
                        
    # 3. Humidity
    hum = data['humidity']
    alert_manager.check("hum_high", hum > THRESH_HUMIDITY_HIGH, 
                        f"High Humidity: {hum:.1f}% (Condensation Risk)", is_critical=False)
                        
    # 4. Light Leak (Lid Closed but Light detected)
    # Lux > 10 and Lid == False (Closed)
    lux = data['lux']
    lid_open = data['lid_open']
    alert_manager.check("light_leak", (not lid_open and lux > THRESH_LIGHT_LEAK), 
                        f"Light Detected ({lux:.1f} lx) while Lid Closed! Hull Breach?", is_critical=True)

# ... (main loop)

    while True:
        # Check Matrix for Commands
        check_matrix_commands()
        
        # ... (read sensors) ...
        
        # Check alerts
        check_sensor_thresholds(data)

        # Logging
        # ...
MATRIX_HOMESERVER = os.getenv("MATRIX_HOMESERVER", "https://matrix.org")
MATRIX_ACCESS_TOKEN = os.getenv("MATRIX_ACCESS_TOKEN", "")
MATRIX_ROOM_ID = os.getenv("MATRIX_ROOM_ID", "")

# --- InfluxDB Config (Env Vars) ---
INFLUX_URL = os.getenv("INFLUX_URL", "http://influxdb:8086")
INFLUX_TOKEN = os.getenv("INFLUX_TOKEN", "")
INFLUX_ORG = os.getenv("INFLUX_ORG", "reduit")
INFLUX_BUCKET = os.getenv("INFLUX_BUCKET", "power")

# --- GPIO Setup ---
GPIO.setmode(GPIO.BCM)
GPIO.setup(PIN_LID_SENSOR, GPIO.IN, pull_up_down=GPIO.PUD_UP)
GPIO.setup(PIN_BUZZER, GPIO.OUT, initial=GPIO.LOW)

def buzz(duration=0.1, count=1):
    """Activates the buzzer."""
    try:
        for _ in range(count):
            GPIO.output(PIN_BUZZER, GPIO.HIGH)
            time.sleep(duration)
            GPIO.output(PIN_BUZZER, GPIO.LOW)
            if count > 1: time.sleep(0.1)
    except: pass

# --- Logging Setup ---
logging.basicConfig(level=logging.INFO, format='%(asctime)s - %(levelname)s - %(message)s')
logger = logging.getLogger(__name__)

# --- InfluxDB Client ---
influx_write_api = None
try:
    if INFLUX_TOKEN:
        influx_client = InfluxDBClient(url=INFLUX_URL, token=INFLUX_TOKEN, org=INFLUX_ORG)
        influx_write_api = influx_client.write_api(write_options=SYNCHRONOUS)
        logger.info(f"InfluxDB Client initialized for {INFLUX_URL}")
    else:
        logger.warning("INFLUX_TOKEN not set. Skipping DB writes.")
except Exception as e:
    logger.error(f"Failed to init InfluxDB: {e}")

# --- DS18B20 Sensor ---
temp_sensor = None
try:
    temp_sensor = W1ThermSensor()
    logger.info(f"DS18B20 Sensor found: {temp_sensor.id}")
except Exception as e:
    logger.warning(f"No DS18B20 sensor found: {e}")

# --- Compass Helper Class (HMC5883L) ---
class Compass:
    def __init__(self, i2c_bus, addr=0x1E):
        self.bus = i2c_bus
        self.addr = addr
        self._init_sensor()

    def _init_sensor(self):
        try:
            while not self.bus.try_lock(): pass
            # 0x00=ConfigA (8-avg,15Hz), 0x01=ConfigB (Gain), 0x02=Mode (Continuous)
            self.bus.writeto(self.addr, bytes([0x00, 0x70]))
            self.bus.writeto(self.addr, bytes([0x01, 0x20]))
            self.bus.writeto(self.addr, bytes([0x02, 0x00]))
            self.bus.unlock()
            logger.info("Compass HMC5883L initialized.")
        except Exception as e:
            logger.error(f"Failed to init Compass: {e}")
            if hasattr(self.bus, 'unlock'): self.bus.unlock()

    def read_heading(self):
        try:
            while not self.bus.try_lock(): pass
            self.bus.writeto(self.addr, bytes([0x03]), stop=False)
            buffer = bytearray(6)
            self.bus.readfrom_into(self.addr, buffer)
            self.bus.unlock()
            x = int.from_bytes(buffer[0:2], byteorder='big', signed=True)
            z = int.from_bytes(buffer[2:4], byteorder='big', signed=True)
            y = int.from_bytes(buffer[4:6], byteorder='big', signed=True)
            heading_rad = math.atan2(y, x)
            if heading_rad < 0: heading_rad += 2 * math.pi
            return math.degrees(heading_rad)
        except Exception as e:
            if hasattr(self.bus, 'unlock'): self.bus.unlock()
            return 0.0

# --- Matrix Helper ---
# ... (imports)

# Global State for Status Command
latest_data = {}
auto_mode_counter = 0 # +ve for Tactical, -ve for Sentry
current_mode = "unknown" # 'sentry', 'tactical', 'manual'

# ... (rest of config) ...

def set_mode_sentry(reason="User Command"):
    """Enables Sentry (Eco) Mode."""
    global current_sample_interval, current_mode
    if current_mode == "sentry": return
    
    set_cpu_governor("powersave")
    set_k8s_scale("tileserver", 0)
    set_wifi_powersave(True)
    current_sample_interval = SAMPLE_INTERVAL_ECO
    current_mode = "sentry"
    send_matrix_alert(f"💤 SENTRY MODE ACTIVE ({reason})")

def set_mode_tactical(reason="User Command"):
    """Enables Tactical (Active) Mode."""
    global current_sample_interval, current_mode
    if current_mode == "tactical": return
    
    set_cpu_governor("ondemand")
    set_k8s_scale("tileserver", 1)
    set_wifi_powersave(False) # Performance WiFi
    current_sample_interval = SAMPLE_INTERVAL_ACTIVE
    current_mode = "tactical"
    send_matrix_alert(f"🚀 TACTICAL MODE ACTIVE ({reason})")

def check_auto_mode(data):
    """Checks power levels and auto-switches modes."""
    global auto_mode_counter
    if not AUTO_MODE_ENABLED: return

    # Current readings
    solar_watts = data.get('solar_watts', 0)
    batt_volts = data.get('system_volts', 0)
    
    # Conditions
    # Go TACTICAL if Solar is abundant OR Battery is very full
    cond_tactical = (solar_watts > THRESH_SOLAR_HIGH) or (batt_volts > THRESH_BATT_HIGH)
    
    # Go SENTRY if Solar is low AND Battery is not full (discharging/low)
    cond_sentry = (solar_watts < THRESH_SOLAR_LOW) and (batt_volts < THRESH_BATT_LOW)
    
    if cond_tactical:
        auto_mode_counter += 1
        if auto_mode_counter > HYSTERESIS_SAMPLES:
            set_mode_tactical(reason="☀️ Energy Abundant")
            auto_mode_counter = HYSTERESIS_SAMPLES # Clamp
    elif cond_sentry:
        auto_mode_counter -= 1
        if auto_mode_counter < -HYSTERESIS_SAMPLES:
            set_mode_sentry(reason="☁️ Energy Saving")
            auto_mode_counter = -HYSTERESIS_SAMPLES # Clamp
    else:
        # Decay counter towards 0 (optional, or just hold state)
        if auto_mode_counter > 0: auto_mode_counter -= 1
        elif auto_mode_counter < 0: auto_mode_counter += 1

def check_matrix_commands():
    """Polls Matrix for new commands (!wifi on/off, !status)."""
    global next_batch_token
    if not MATRIX_ACCESS_TOKEN or not MATRIX_ROOM_ID: return

    try:
        url = f"{MATRIX_HOMESERVER}/_matrix/client/r0/sync"
        params = {"timeout": 0, "filter": '{"room":{"rooms":["' + MATRIX_ROOM_ID + '"]}}'}
        if next_batch_token: params["since"] = next_batch_token
        
        headers = {"Authorization": f"Bearer {MATRIX_ACCESS_TOKEN}"}
        resp = requests.get(url, params=params, headers=headers, timeout=5)
        
        if resp.status_code == 200:
            data = resp.json()
            next_batch_token = data.get("next_batch")
            
            rooms = data.get("rooms", {}).get("join", {}).get(MATRIX_ROOM_ID, {})
            timeline = rooms.get("timeline", {}).get("events", [])
            
            for event in timeline:
                if event.get("type") == "m.room.message":
                    body = event.get("content", {}).get("body", "").strip().lower()
                    if body == "!wifi off":
                        set_wifi(False)
                    elif body == "!wifi on":
                        set_wifi(True)
                    elif body == "!maps off":
                        set_k8s_scale("tileserver", 0)
                    elif body == "!maps on":
                        set_k8s_scale("tileserver", 1)
                    elif body == "!eco on":
                        set_mode_sentry()
                    elif body == "!eco off":
                        set_mode_tactical()
                    elif body == "!auto on":
                        global AUTO_MODE_ENABLED
                        AUTO_MODE_ENABLED = True
                        send_matrix_alert("🔄 Dynamic Power Switching: ENABLED")
                        buzz(0.1, 2)
                    elif body == "!auto off":
                        global AUTO_MODE_ENABLED
                        AUTO_MODE_ENABLED = False
                        # Reset counter to zero to avoid stuck state if re-enabled
                        global auto_mode_counter
                        auto_mode_counter = 0
                        send_matrix_alert("🛑 Dynamic Power Switching: DISABLED (Manual Mode Only)")
                        buzz(0.5)
                    elif body == "!status":
                        send_status_report()
    except Exception as e:
        logger.error(f"Matrix Sync Fail: {e}")

def set_wifi_powersave(enable):
    """Sets WiFi Power Save mode."""
    state = "on" if enable else "off"
    try:
        subprocess.run(["iw", "dev", WIFI_INTERFACE, "set", "power_save", state], check=True)
        logger.info(f"WiFi Power Save set to {state}")
    except Exception as e:
        logger.error(f"WiFi PS Failed: {e}")

def set_tx_power(dbm):
    """Sets WiFi Transmission Power Limit."""
    try:
        # 'iw dev wlan1 set txpower fixed 1000' (1000mBm = 10dBm)
        mBm = dbm * 100
        subprocess.run(["iw", "dev", WIFI_INTERFACE, "set", "txpower", "fixed", str(mBm)], check=True)
        logger.info(f"WiFi TxPower set to {dbm}dBm")
    except Exception as e:
        logger.error(f"Set TxPower Failed: {e}")

def set_usb_power(enable):
    """Controls power to the USB device via Driver Bind/Unbind."""
    if not WIFI_USB_ID or not WIFI_DRIVER_PATH:
        logger.warning("Deep Sleep skipped: WIFI_USB_ID or WIFI_DRIVER_PATH not set.")
        return

    action = "bind" if enable else "unbind"
    path = os.path.join(WIFI_DRIVER_PATH, action)
    
    try:
        # Check if already in desired state to avoid errors
        dev_path = os.path.join(WIFI_DRIVER_PATH, WIFI_USB_ID)
        is_bound = os.path.exists(dev_path)
        
        if enable and is_bound: return
        if not enable and not is_bound: return

        logger.info(f"WiFi Deep Sleep: {action}ing {WIFI_USB_ID}...")
        with open(path, "w") as f:
            f.write(WIFI_USB_ID)
    except Exception as e:
        logger.error(f"USB Power {action} Failed: {e}")

def set_k8s_scale(deployment, replicas):
    """Scales a k8s deployment to save power."""
    try:
        # Assumes running as root with kubectl access or KUBECONFIG set
        cmd = ["kubectl", "scale", "deployment", deployment, f"--replicas={replicas}", "-n", "default"]
        subprocess.run(cmd, check=True)
        send_matrix_alert(f"⚖️ Scaled {deployment} to {replicas} replicas.")
        buzz(0.1, 1)
    except Exception as e:
        logger.error(f"Scale Failed: {e}")
        send_matrix_alert(f"⚠️ Scale Failed: {e}")

def set_cpu_governor(mode):
    """Sets CPU Governor (powersave|ondemand|performance)."""
    # modes: powersave (min freq), ondemand (jumpy), performance (max)
    try:
        # RPi specific: write to all cores
        # We use a shell command with wildcard expansion
        subprocess.run(f"echo {mode} | tee /sys/devices/system/cpu/cpu*/cpufreq/scaling_governor", shell=True, check=True)
        send_matrix_alert(f"🧠 CPU Governor set to: {mode.upper()}")
        buzz(0.1, 1)
    except Exception as e:
        logger.error(f"CPU Gov Failed: {e}")
        send_matrix_alert(f"⚠️ CPU Gov Failed: {e}")

def send_status_report():
    if not latest_data:
        send_matrix_alert("⚠️ Status: No sensor data available yet.")
        return
        
    d = latest_data
    # Get current CPU Gov
    try:
        with open("/sys/devices/system/cpu/cpu0/cpufreq/scaling_governor", "r") as f:
            gov = f.read().strip()
    except: gov = "?"

    msg = (f"🔋 **Power**: {d.get('system_volts',0):.2f}V | {d.get('net_watts',0):.1f}W Net\n"
           f"🌡️ **Climate**: {d.get('temperature',0):.1f}°C | {d.get('humidity',0):.0f}% | {d.get('pressure',0):.0f}hPa\n"
           f"🧠 **System**: Mode: {current_mode.upper()} | CPU: {gov}\n"
           f"💡 **Light/Lid**: {d.get('lux',0):.0f} lx | Lid: {'OPEN' if d.get('lid_open') else 'Closed'}\n"
           f"🧭 **Heading**: {d.get('heading',0):.0f}°")
    send_matrix_alert(msg)

# ... (set_wifi, get_temperature, write_to_influx, initialize_sensors, log_to_csv) ...

def main():
    global latest_data
    i2c = busio.I2C(board.SCL, board.SDA)
    # ... (init sensors) ...
    
    hostname = socket.gethostname()
    buzz(0.1, 2)
    send_matrix_alert(f"🟢 Monitor Online on {hostname}. Audio & Sensors Active.")
    buzz(0.1, 2)
    send_matrix_alert(f"🟢 Monitor Online on {hostname}. Audio & Sensors Active.")
    logger.info("Starting Power Monitor Loop...")

    # Initial WiFi Config
    set_tx_power(WIFI_TXPOWER_DBM)
    set_wifi_powersave(True)

    low_voltage_counter = 0
    last_accel = None
    last_lid_state = False 

    while True:
        # Check Matrix for Commands
        check_matrix_commands()

        data = {
            'timestamp': datetime.now().isoformat(),
            'solar_volts': 0.0, 'solar_amps': 0.0, 'solar_watts': 0.0,
            'system_volts': 0.0, 'system_amps': 0.0, 'system_watts': 0.0,
            'net_watts': 0.0, 'temperature': 0.0, 'humidity': 0.0, 'pressure': 0.0,
            'lid_open': False, 'heading': 0.0, 'lux': 0.0
        }

        # ... (Sensor Reading Logic same as before) ...
        # ... (0. Check Lid) ...
        # ... (1. Read Temp) ...
        # ... (2. Read Power) ...
        # ... (3. Read Environment) ...
        # ... (4. Read Compass) ...
        # ... (5. Check Motion) ...
        
        # [OMITTED FOR BREVITY - KEEP EXISTING READING CODE]

        # Update Global State for !status command
        latest_data = data
        
        # Export for TAK Bridge (IPC)
        try:
            with open("/tmp/reduit_status.json", "w") as f:
                json.dump(data, f)
        except: pass
        
        # Check Thresholds
        check_sensor_thresholds(data)
        
        # Check Auto Mode
        check_auto_mode(data)
        
        # Logging
        # ... (rest of loop) ...

def set_wifi(state):
    """Toggles WiFi Interface and USB Power."""
    cmd = "up" if state else "down"
    try:
        if state:
            # Wake up: 1. Power on USB, 2. Link up, 3. Config
            set_usb_power(True)
            time.sleep(2) # Wait for device to enumerate
            subprocess.run(["ip", "link", "set", WIFI_INTERFACE, cmd], check=True)
            time.sleep(1)
            set_tx_power(WIFI_TXPOWER_DBM)
            set_wifi_powersave(True)
            send_matrix_alert(f"📶 WiFi {WIFI_INTERFACE} is now UP (Active).")
        else:
            # Sleep: 1. Link down, 2. Power off USB
            subprocess.run(["ip", "link", "set", WIFI_INTERFACE, cmd], check=True)
            set_usb_power(False)
            send_matrix_alert(f"💤 WiFi {WIFI_INTERFACE} is now DOWN (Deep Sleep).")
            
        buzz(0.1, 1) # Confirm beep
    except Exception as e:
        send_matrix_alert(f"⚠️ Failed to set WiFi {cmd}: {e}")

def get_temperature():
    if not temp_sensor: return 0.0
    try: return temp_sensor.get_temperature()
    except: return 0.0

def write_to_influx(data):
    if not influx_write_api: return
    try:
        p = Point("power_metrics") \
            .tag("host", socket.gethostname()) \
            .field("solar_volts", data['solar_volts']) \
            .field("solar_amps", data['solar_amps']) \
            .field("solar_watts", data['solar_watts']) \
            .field("system_volts", data['system_volts']) \
            .field("system_amps", data['system_amps']) \
            .field("system_watts", data['system_watts']) \
            .field("net_watts", data['net_watts']) \
            .field("temperature_c", data['temperature']) \
            .field("humidity_pct", data.get('humidity', 0.0)) \
            .field("pressure_hpa", data.get('pressure', 0.0)) \
            .field("lux", data.get('lux', 0.0)) \
            .field("heading_deg", data.get('heading', 0.0)) \
            .field("lid_open", int(data.get('lid_open', 0))) \
            .time(datetime.utcnow(), WritePrecision.NS)
        influx_write_api.write(bucket=INFLUX_BUCKET, org=INFLUX_ORG, record=p)
    except Exception as e:
        logger.error(f"Influx Write Failed: {e}")
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

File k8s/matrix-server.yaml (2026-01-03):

apiVersion: apps/v1
kind: Deployment
metadata:
  name: matrix-server
  namespace: default
  labels:
    app: matrix-server
spec:
  replicas: 1
  selector:
    matchLabels:
      app: matrix-server
  template:
    metadata:
      labels:
        app: matrix-server
    spec:
      containers:
      - name: conduit
        image: matrixconduit/matrix-conduit:latest
        imagePullPolicy: IfNotPresent
        ports:
        - containerPort: 8008
          name: client
        - containerPort: 8448
          name: federation
        env:
        - name: CONDUIT_SERVER_NAME
          value: "reduit.local" # Change this to your real domain
        - name: CONDUIT_DATABASE_PATH
          value: "/var/lib/matrix-conduit"
        - name: CONDUIT_PORT
          value: "8008"
        - name: CONDUIT_ALLOW_REGISTRATION
          value: "true"
        volumeMounts:
        - name: matrix-data
          mountPath: /var/lib/matrix-conduit
      volumes:
      - name: matrix-data
        persistentVolumeClaim:
          claimName: matrix-data-pvc
---
apiVersion: v1
kind: Service
metadata:
  name: matrix-server
  namespace: default
spec:
  selector:
    app: matrix-server
  ports:
  - protocol: TCP
    port: 8008
    targetPort: 8008
    name: client
  - protocol: TCP
    port: 8448
    targetPort: 8448
    name: federation
---
apiVersion: v1
kind: PersistentVolumeClaim
metadata:
  name: matrix-data-pvc
  namespace: default
spec:
  accessModes:
    - ReadWriteOnce
  resources:
    requests:
      storage: 1Gi

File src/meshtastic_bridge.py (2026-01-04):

import os
import time
import asyncio
import yaml
import logging
import meshtastic.serial_interface
from meshtastic import mesh_pb2
from nio import AsyncClient, MatrixRoom, RoomMessageText
import subprocess

# Configure Logging
logging.basicConfig(level=logging.INFO, format='%(asctime)s - %(name)s - %(levelname)s - %(message)s')
logger = logging.getLogger("MeshtasticBridge")

# Configuration Path
CONFIG_PATH = os.environ.get("BRIDGE_CONFIG", "/etc/meshtastic-bridge/config.yaml")

class MeshtasticMatrixBridge:
    def __init__(self, config):
        self.config = config
        self.matrix_client = None
        self.mesh_interface = None
        self.room_id = config['matrix']['room_id']

    async def start_matrix(self):
        logger.info(f"Connecting to Matrix Homeserver: {self.config['matrix']['homeserver']}")
        self.matrix_client = AsyncClient(
            self.config['matrix']['homeserver'],
            self.config['matrix']['user_id']
        )
        self.matrix_client.access_token = self.config['matrix']['access_token']
        
        # Verify connection
        whoami = await self.matrix_client.whoami()
        logger.info(f"Matrix Connected as: {whoami}")

        # Join Room
        await self.matrix_client.join(self.room_id)
        logger.info(f"Joined Room: {self.room_id}")

        # Start Sync Loop to receive commands
        self.matrix_client.add_event_callback(self.on_matrix_message, RoomMessageText)
        asyncio.create_task(self.matrix_client.sync_forever(timeout=30000))

    def start_meshtastic(self):
        logger.info("Connecting to Meshtastic Node...")
        meshtastic_conf = self.config['meshtastic']
        connection_type = meshtastic_conf.get('connection_type', 'serial')

        if connection_type == 'network':
            host = meshtastic_conf['network']['host']
            port = meshtastic_conf['network'].get('port', 4403)
            import meshtastic.tcp_interface
            self.mesh_interface = meshtastic.tcp_interface.TCPInterface(host, port)
            logger.info(f"Connected to Meshtastic via TCP: {host}:{port}")
        else:
            # Fallback to serial
            serial_config = meshtastic_conf.get('serial', {})
            port = serial_config.get('port', '/dev/ttyUSB0')
            self.mesh_interface = meshtastic.serial_interface.SerialInterface(devPath=port)
            logger.info(f"Connected to Meshtastic via Serial: {port}")
        
        # Subscribe to messages
        from pubsub import pub
        pub.subscribe(self.on_meshtastic_message, "meshtastic.receive")

    async def on_matrix_message(self, room: MatrixRoom, event: RoomMessageText):
        if room.room_id != self.room_id:
            return

        body = event.body.strip()
        sender = event.sender
        logger.info(f"Matrix Message received from {sender}: {body}")
        
        # Matrix Auth Check
        allowed_users = self.config.get('security', {}).get('allowed_matrix_users', [])
        if allowed_users and sender not in allowed_users:
            logger.warning(f"Unauthorized Matrix command attempt from {sender}")
            return

        await self.process_command(body, "Matrix")

    def on_meshtastic_message(self, packet, interface):
        try:
            if 'decoded' in packet:
                decoded = packet['decoded']
                if decoded.get('portnum') == 'TEXT_MESSAGE_APP':
                    text_content = decoded.get('text', '')
                    sender = packet.get('fromId', 'Unknown')
                    
                    if text_content:
                        logger.info(f"Received from Mesh: {sender}: {text_content}")
                        
                        # Process Command
                        if text_content.startswith("!"):
                            asyncio.run_coroutine_threadsafe(
                                self.process_command_lora(text_content, sender),
                                self.loop
                            )

                        # Forward to Matrix
                        asyncio.run_coroutine_threadsafe(
                             self.send_to_matrix(f"**[{sender}]**: {text_content}"),
                             self.loop
                        )
        except Exception as e:
            logger.error(f"Error processing packet: {e}")

    async def process_command_lora(self, text, sender):
        # LoRa Auth Check (PIN)
        pin = self.config.get('security', {}).get('admin_pin')
        
        if not pin:
             # No PIN configured -> Locked by default or Insecure? Let's default to requiring PIN if sec section exists
             logger.warning("LoRa command ignored: No admin_pin configured.")
             return

        # Expect format: !<PIN> <CMD>  e.g., !1234 wifi on
        parts = text.split(' ', 1)
        if len(parts) < 2:
            return # Malformed

        cmd_pin_part = parts[0] # "!1234"
        command_body = "!" + parts[1] # "!wifi on"

        if cmd_pin_part == f"!{pin}":
            logger.info(f"LoRa Auth Success for {sender}")
            await self.process_command(command_body, f"Mesh User {sender}")
        else:
            logger.warning(f"LoRa Auth Failed for {sender}. Invalid PIN.")

    async def process_command(self, body, source):
        cmd = body.lower()
        if not cmd.startswith("!"):
            return

        logger.info(f"Processing command from {source}: {cmd}")

        if cmd == "!lte on":
            await self.toggle_interface(self.config.get('lte_interface', 'wwan0'), True, "LTE")
        elif cmd == "!lte off":
            await self.toggle_interface(self.config.get('lte_interface', 'wwan0'), False, "LTE")
            
        elif cmd == "!wifi on":
            await self.toggle_interface(self.config.get('wifi_interface', 'wlan1'), True, "High-Power WiFi")
        elif cmd == "!wifi off":
            await self.toggle_interface(self.config.get('wifi_interface', 'wlan1'), False, "High-Power WiFi")
            
        elif cmd == "!eco on":
            await self.send_to_matrix("🍃 Activating ECO Mode (Disabling LTE & High-Power WiFi)...")
            await self.toggle_interface(self.config.get('lte_interface', 'wwan0'), False, "LTE")
            await self.toggle_interface(self.config.get('wifi_interface', 'wlan1'), False, "High-Power WiFi")
            
        elif cmd == "!status":
             await self.report_status()
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

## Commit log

2026-01-02 Add README.md for Le Réduit project
    Added comprehensive documentation for the Le Réduit project, detailing its purpose, features, hardware components, wiring architecture, software stack, safety notes, and contribution guidelines.
2026-01-02 Revise README for solar panel specs and safety notes
    Updated specifications for solar panel and charging connections, corrected language inconsistencies, and improved clarity in safety warnings.
2026-01-03 feat: Introduce initial Le Reduit power monitoring system with application, hardware scripts, documentation, and Kubernetes deployment.
2026-01-03 feat: add painting guide, implement Matrix alerts and low-voltage shutdown in power monitor, and update its Kubernetes deployment.
2026-01-03 feat: Add GPS-to-TAK bridge, Kubernetes manifests for monitoring and map services, and update documentation for new sensors and power estimates.
2026-01-04 feat: Implement full Le Reduit stack deployment via Helm chart, including Meshtastic, maps, and Matrix, with new hardware optimization and installation scripts, and updated power estimates.
2026-01-04 feat: implement dynamic power management with auto-switching modes, enhanced WiFi deep sleep, and translated README tagline
2026-01-04 feat: Upgrade power system from AGM battery to LiFePO4 battery and Victron SmartSolar MPPT controller.
2026-01-12 feat: add RNode (Heltec v3) support and update wiring schema
    - Add k8s/rnode.yaml for Reticulum RNode deployment
    - Update wiring_schema.md:
    - Add RNode on USB 3.0 (Bottom) with own SMA antenna
    - Restore WiFi stick on USB 2.0 (Top)
    - Clarify USB port assignments for full capacity usage
2026-01-19 feat: Transition platform to 3D printed modular design, adding a printing guide and removing the painting guide.
2026-01-31 docs: Enhance Heltec LoRa mounting details, add component material specifics, adhesive thermal warnings, and Bambu Lab printer-specific tips.
2026-01-31 feat: add initial CAD models, renders, and generation script for the LeReduit project.
    [foundation.scad, joiner_cross.stl, joiner_strip.stl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]
2026-01-31 Update generated STL parts and remove joiner part generation from the build script.
    [foundation.scad, part_1_top_left.stl, part_2_top_right.stl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]

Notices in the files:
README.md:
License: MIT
